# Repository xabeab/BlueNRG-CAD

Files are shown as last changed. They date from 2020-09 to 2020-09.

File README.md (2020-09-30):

BlueNRG-CAD
======
CAD files to produce the mechanical enclosure and circuits for a BLE device monitoring movement.

The mechanical parts were designed using CATIA. A student license is necessary to open the files. The STL files are available for 3D printing using PLA. 
The ACM_base_1 part is compatible with AppleWatch bands serie 4. It should be used for ankles and wrists.
The ACM_base_2 can be attached to a belt or any piece of thick clothing.

The circuit was designed using KiCad. All GERBER files are available for immediate production. A battery of around 160 mAh should be connected using a JST connector. 

This repository is part of the Activity Recognition based on Movement project, which is a complete open-source hardware and software solution of wearable BLE accelerometers + gyroscopes allowing activity recognition.

License
-------
This files are released into the public domain by its author, Xavier Beaulé.

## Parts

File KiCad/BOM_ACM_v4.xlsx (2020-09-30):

Item # | *Ref Des | *Qty | Manufacturer | *Mfg Part # | Description / Value | *Package | Type | Your Instructions / Notes
1 | U1 | 1 | STMicroelecronics | LSM6DS3TR | IMU ACCEL/GYRO I2C/SPI 14VFLGA | 14VFLGA | SMD
2 | U2 | 1 | STMicroelecronics | SPBTLE-1S | SYSTEM PRODUCT & MODULE | MODULE | SMD
3 | U3 | 1 | Texas Instruments | ‎TLV70033DDCR | IC REG LINEAR 3.3V 200MA SOT23-5 | SOT23-5 | SMD
4 | U4 | 1 | Texas Instruments | BQ24232RGTR | IC LI-ION CHARGE PWR MGMT 16QFN | VQFN | SMD
5 | TL3305A1 | 1 | E-SWITCH | TL3305AF160QG | SWITCH TACTILE SPST-NO 50MA 12V | N/A | SMD
6 | R1 | 1 | Yageo | RC0603JR-07680RL | RES SMD 680 OHM 5% 1/10W 0603 | 0603 | SMD
7 | R2, R3 | 2 | Yageo | RC0603JR-07100KL | RES SMD 100K OHM 5% 1/10W 0603 | 0603 | SMD
8 | R6 | 1 | Yageo | RC0603FR-0711K5L | RES SMD 11.5K OHM 1% 1/10W 0603 | 0603 | SMD
9 | R7 | 1 | Yageo | RC0603FR-0710KL | RES SMD 10K OHM 1% 1/10W 0603 | 0603 | SMD
10 | R8, R9 | 2 | Yageo | RC0603FR-072KL | RES SMD 2K OHM 1% 1/10W 0603 | 0603 | SMD
8 | C1 | 1 | Samsung Electro-Mechanics | CL10B225KP8NNNC | CAP CER 2.2UF 10V X7R 0603 | 0603 | SMD
9 | C2, C3, C4 | 3 | Yageo | CC0603KRX7R8BB104 | CAP CER 0.1UF 25V X7R 0603 | 0603 | SMD
10 | C5 | 1 | Samsung Electro-Mechanics | CL10B103KB8NCNC | CAP CER 10000PF 50V X7R 0603 | 0603 | SMD
11 | C6, C7, C8 | 3 | Samsung Electro-Mechanics | CL10B105KP8NNNC | CAP CER 1UF 10V X7R 0603 | 0603 | SMD
12 | C9, C10 | 2 | Samsung Electro-Mechanics | CL10A475KP8NNNC | CAP CER 4.7UF 10V X5R 0603 | 0603 | SMD
13 | D1, D2, D3 | 3 | Lite-On Inc.‎ | ‎LTST-C171GKT | LED GREEN CLEAR CHIP SMD | 0805 | SMD
14 | J2 | 1 | Molex | 1050170001 | CONN RCPT USB2.0 MICRO B SMD R/A | N/A | SMD
15 | J3 | 1 | JST Sales America Inc. | S2B-PH-SM4-TB(LF)(SN) | CONN HEADER SMD R/A 2POS 2MM | N/A | SMD

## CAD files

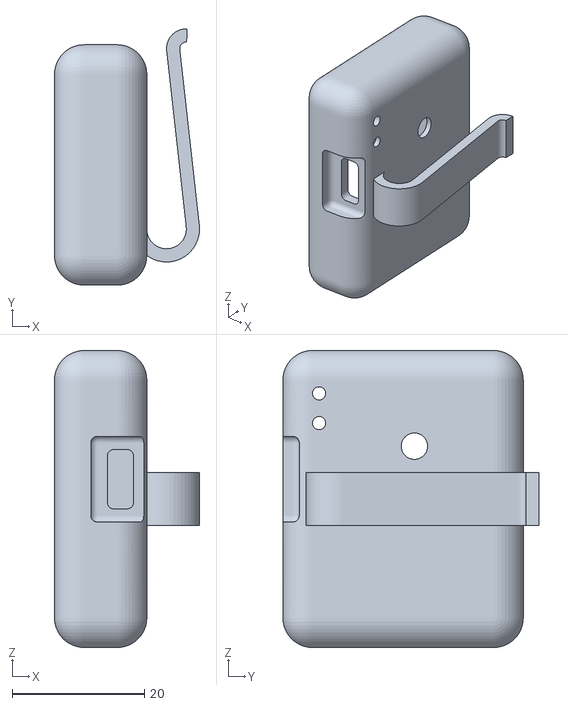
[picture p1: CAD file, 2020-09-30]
Catia/ACM_base_2.stl
22.0 x 38.8 x 45.0

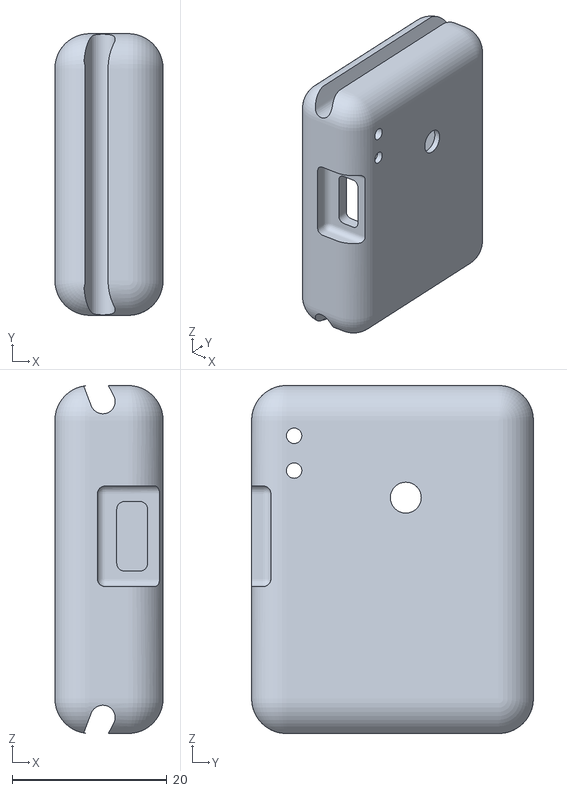
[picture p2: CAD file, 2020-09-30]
Catia/ACM_base_1.stl
14.0 x 36.4 x 45.0

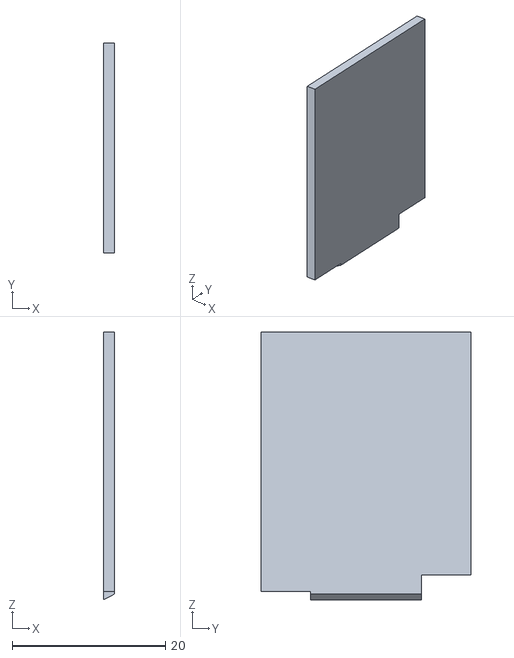
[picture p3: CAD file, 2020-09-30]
Catia/ACM_cover.stl
1.50 x 27.4 x 35.0

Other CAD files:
KiCad/Librairies/kicad-footprints-master/kicad-footprints-master/Sources/Inductor_SMD/L_Coilcraft_LPS5030.FCStd
KiCad/Librairies/kicad-footprints-master/kicad-footprints-master/Sources/Package_SON/X2SON-4_1x1mm_P0.65mm.fcstd
KiCad/Librairies/kicad-footprints-master/kicad-footprints-master/Sources/Package_TO_SOT_THT/sod-70.fcstd
KiCad/Librairies/kicad-footprints-master/kicad-footprints-master/Sources/Package_TO_SOT_THT/sod-70_P5.08mm.fcstd
Catia/Apple Watch Lug Profile R3.dwg
Catia/ACM_base_1.CATPart
Catia/ACM_base_2.CATPart
Catia/ACM_cover.CATPart
Catia/Part1.CATPart
Catia/Part2.CATPart

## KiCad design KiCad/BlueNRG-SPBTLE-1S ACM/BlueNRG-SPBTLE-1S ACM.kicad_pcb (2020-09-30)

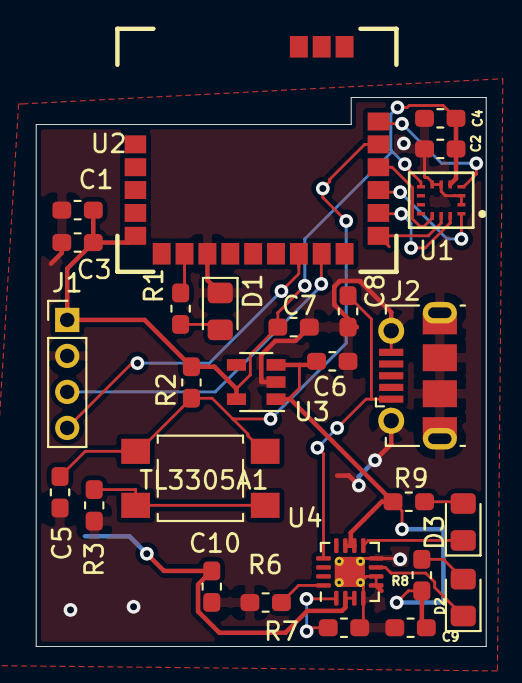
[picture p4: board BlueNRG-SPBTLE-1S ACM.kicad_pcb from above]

Board: 2 copper layers, 25.0 x 30.5 mm, 28 parts (1 on the bottom side), 22 nets.

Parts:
C1: 2.2u; C_0603_1608Metric_Pad1.05x0.95mm_HandSolder
C2, C3, C4: 100n; C_0603_1608Metric_Pad1.05x0.95mm_HandSolder
C5: 10n; C_0603_1608Metric_Pad1.05x0.95mm_HandSolder
C6, C7, C8: 1u; C_0603_1608Metric_Pad1.05x0.95mm_HandSolder
C9, C10: 4.7u; C_0603_1608Metric_Pad1.05x0.95mm_HandSolder
D1, D2, D3: LED; LED_0805_2012Metric_Pad1.15x1.40mm_HandSolder
J1: Conn_01x04_Female; Socket_Strip_Straight_1x04_Pitch2.00mm
J2: USB_B_Micro; USB_Micro-B_Molex-105017-0001
J3: Conn_01x02_Female; JST_PH_S2B-PH-SM4-TB_1x02-1MP_P2.00mm_Horizontal
R1: 680; R_0603_1608Metric_Pad1.05x0.95mm_HandSolder
R2, R3: 100k; R_0603_1608Metric_Pad1.05x0.95mm_HandSolder
R6: 11.5k; R_0603_1608Metric_Pad1.05x0.95mm_HandSolder
R7: 10k; R_0603_1608Metric_Pad1.05x0.95mm_HandSolder
R8, R9: 2k; R_0603_1608Metric_Pad1.05x0.95mm_HandSolder
TL3305A1: SW_Push_Dual; SW_SPST_TL3305A
U1: LSM6DS3
U2: SPBTLE-1S-Custom_Library; SPBTLE-1S
U3: TLV70033_SOT23-5; SOT-23-5
U4: BQ24232; VQFN-16-1EP_3x3mm_P0.5mm_EP1.68x1.68mm_ThermalVias

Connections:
DIO12-INT: U1.4, U2.20
GND: C1.2, C2.1, C3.2, C4.2, C5.2, C6.1, C7.2, C8.2, C9.1, C10.1, D1.1, J1.2, J2.5, J2.6, J3.2, R3.2, R6.1, R7.2, U1.2, U1.3, U1.6, U1.7, U2.8, U3.2, U4.4, U4.5, U4.6, U4.8, U4.17
JTCK-SWCTK: J1.4, U2.12
JTMS-SWTDIO: J1.3, U2.13
unnamed: C5.1, R2.2, TL3305A1.2, U2.19
unnamed: C8.1, J2.1, U4.13
unnamed: C10.2, J3.1, U4.2, U4.3
unnamed: D1.2, R1.2
unnamed: D2.1, U4.7
unnamed: D2.2, R8.1
unnamed: D3.1, U4.9
unnamed: D3.2, R9.1
unnamed: R1.1, U2.7
unnamed: R3.1, TL3305A1.1
unnamed: R6.2, U4.16
unnamed: R7.1, U4.1
SPI_CLK: U1.13, U2.15
SPI_CS: U1.12, U2.18
SPI_IN: U1.1, U2.17
SPI_OUT: U1.14, U2.16
VOUT_BQ: C6.2, C9.2, R8.2, R9.2, U3.1, U3.3, U4.10, U4.11
Vdd: C1.1, C2.2, C3.1, C4.1, C7.1, J1.1, R2.1, U1.5, U1.8, U2.5, U3.5

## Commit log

2019-02-18 Initial relase. Working on the PCB for the BlueNRG-2
    [familylist_refdes.csv]
2019-03-03 Initial push for the SPBTLE-1S
    [BlueNRG-SPBTLE-1S ACM.kicad_pcb, BlueNRG-SPBTLE-1S ACM.sch]
2019-03-04 Initial PCB design done
    [BlueNRG-SPBTLE-1S ACM.sch]
2019-03-05 Added a push button for the RST pin and an IC for the power management
    [BlueNRG-SPBTLE-1S ACM.kicad_pcb, BlueNRG-SPBTLE-1S ACM.sch, L_Coilcraft_LPS5030.FCStd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]
2019-03-05 Generated the gbr files for the 1st print
    [BlueNRG-SPBTLE-1S ACM-B.Cu.gbr, BlueNRG-SPBTLE-1S ACM-B.Mask.gbr, BlueNRG-SPBTLE-1S ACM-B.Paste.gbr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]
2019-03-18 Enclosure design using Catia
    [Part1.CATPart, Part2.CATPart, eight_print.stl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]
2019-03-19 Part 3 and 4 based on the Apple Watch
    [Part3.CATPart, Part4.CATPart, eight_print.stl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]
2019-03-26 Improved the tolerances for the white PLA
    [1.stl, 2.stl, Part3.CATPart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]
2019-04-02 The cover now is even with the rest of the enclosure
    [2.stl, Part4.CATPart]
2019-04-11 Changed the band profile to the official one from Apple
    [1.stl, 2.stl, Apple Watch Lug Profile R3.dwg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]
2019-05-06 Made the necessary modifications for ACM v2 (circuit logic to Vbat, Vdd to SPTBLE)
    [BlueNRG-SPBTLE-1S ACM.kicad_pcb, BlueNRG-SPBTLE-1S ACM.sch]
2020-09-30 The first version is completed
    [BlueNRG-SPBTLE-1S ACM.sch]
2020-09-30 Added charging capabilities to ACM PCB and removed the screws. Removed the screws from the cover
    [BOM.xlsx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]
2020-09-30 Modified the charging feature
    [BlueNRG-SPBTLE-1S ACM.kicad_pcb, BlueNRG-SPBTLE-1S ACM.sch]
2020-09-30 Smaller pcb. Also added charging feature
    [Part4.CATPart]
2020-09-30 Fixed the PCB layout and schematic for the charger U
    [BlueNRG-SPBTLE-1S ACM-B.Cu.gbr, BlueNRG-SPBTLE-1S ACM-B.Mask.gbr, BlueNRG-SPBTLE-1S ACM-B.Paste.gbr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]
2020-09-30 Changed the female connector for the battery. Changed the BQ circuitry
    [BlueNRG-SPBTLE-1S ACM.kicad_pcb]
2020-09-30 Few changes before order
    [BlueNRG-SPBTLE-1S ACM-B.Cu.gbr, BlueNRG-SPBTLE-1S ACM-B.Mask.gbr, BlueNRG-SPBTLE-1S ACM-B.SilkS.gbr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]
2020-09-30 Added BOM
    [BOM.xlsx, BOM_ACM_v4.xlsx]
2020-09-30 Made changes to fit the new battery
    [ACM_base.CATPart, ACM_cover.CATPart, Part3.CATPart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]
2020-09-30 Added holes to displays charging statue. Improved the fiting of the top part of the pieces
    [ACM_cover.CATPart]
2020-09-30 Removed junk files. Added stl.
    [1.stl, ACM_base.stl, ACM_cover.stl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]
2020-09-30 Moved files up one folder
    [BOM_ACM_v4.xlsx, BlueNRG-SPBTLE-1S ACM.kicad_pcb, BlueNRG-SPBTLE-1S ACM.sch]
2020-09-30 Added a part for wearability on the belt
    [ACM_base_1.CATPart, ACM_base_1.stl, ACM_base_2.CATPart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]
2020-09-30 Moved the librairies folder into the kicad folder
    [L_Coilcraft_LPS5030.FCStd, X2SON-4_1x1mm_P0.65mm.fcstd, familylist_refdes.csv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]
